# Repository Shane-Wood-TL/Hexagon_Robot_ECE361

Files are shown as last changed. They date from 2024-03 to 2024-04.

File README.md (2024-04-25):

# Hexagon Robot ECE361
 
### Shane Wood and Logan Martin 

### Final Robot
1PXL_20240423_235646060 RAW-01 COVER

### Early Render of robot
robo2

### Abstract: 
For this design project, we are planning to develop a robotics platform by creating a 3-wheeled robot. This design also includes a controller so the robot can be controlled remotely over 2.4 GHz using an NRF2401 module. Our design currently has 3 main modes planned; user control with the controller, fully autonomous (wall following), and line following. We plan to use the ESP32-S3 for the microcontrollers running on the Arduino framework for both the controller and the robot. The robot will also feature distance sensors for the autonomous modes and IR sensors for the line-following mode. The robot will have a 3d printed base and omni wheels, the project will also have 2 custom PCBs, one for the robot itself and the other for the controller. 

### Weekly Goals: 
Week of March 18th  
- Make the wiring diagram 
- Set up GitHub repository 
- 3d print wheel pieces 

Week of March 25th 
- Wire up design 
- Simple test code to verify wiring and power management 
- Design and order PCBs 
- Assemble wheels 

Week of April 1st 
- Develop the inverse kinematic model 
- Make controller code 
- 3d print robot body 

Week of April 8th 
- Finish user code mode 
- Get distance sensors and IR sensors working 

Week of April 15th 
- Test and finish all modes and the logic to switch between them 

Week of April 22nd 
- Debug remaining issues

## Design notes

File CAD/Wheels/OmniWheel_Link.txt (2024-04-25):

https://www.thingiverse.com/thing:5031000

Scaled to 175%
PLA for wheel body pieces

TPU 95A for rollers

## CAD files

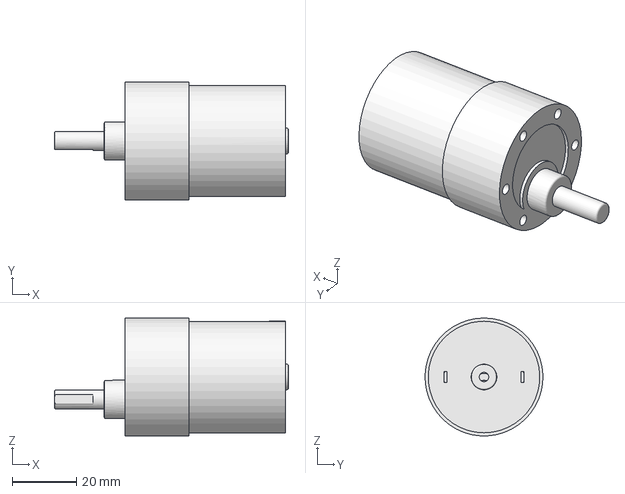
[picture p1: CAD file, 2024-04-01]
CAD/Body/assembly.FCStd
73.0 x 36.8 x 36.8 mm

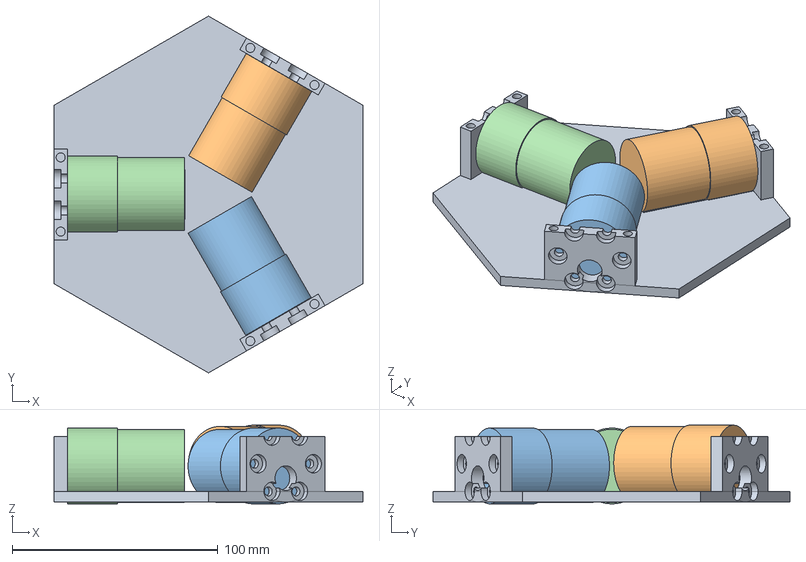
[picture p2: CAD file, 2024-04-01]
CAD/Body/oldbottom plate.FCStd
150.0 x 173.2 x 38.2 mm

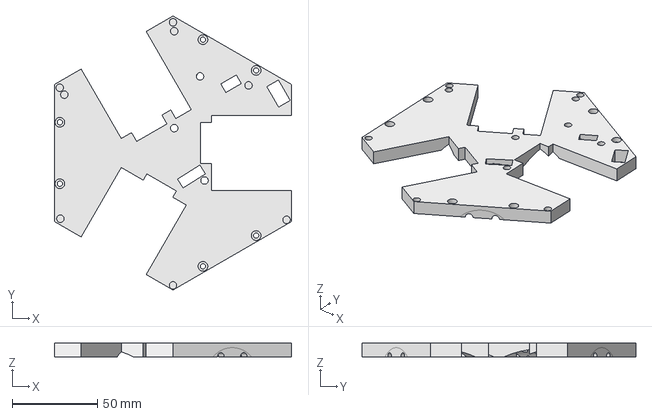
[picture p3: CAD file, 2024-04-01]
CAD/Body/2topplate.FCStd
139.0 x 160.5 x 8.00 mm

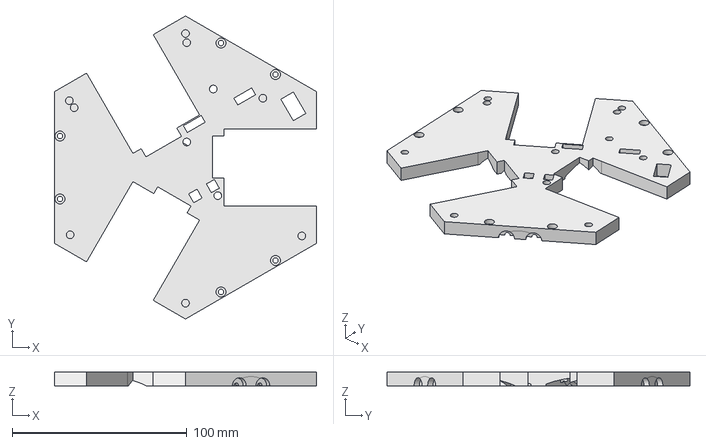
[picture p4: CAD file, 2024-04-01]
CAD/Body/topplate.FCStd
150.0 x 173.2 x 8.00 mm

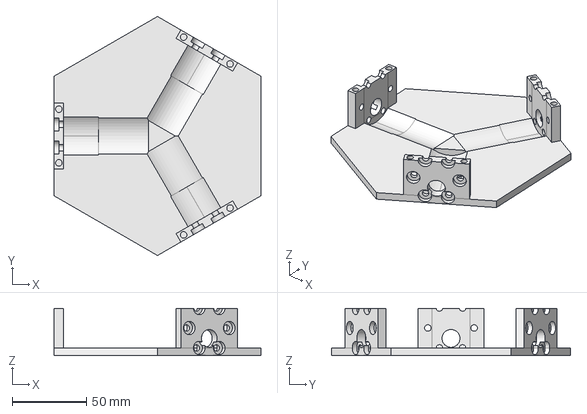
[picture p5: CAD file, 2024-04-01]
CAD/Body/V2bottom plate.FCStd
139.0 x 160.5 x 31.8 mm

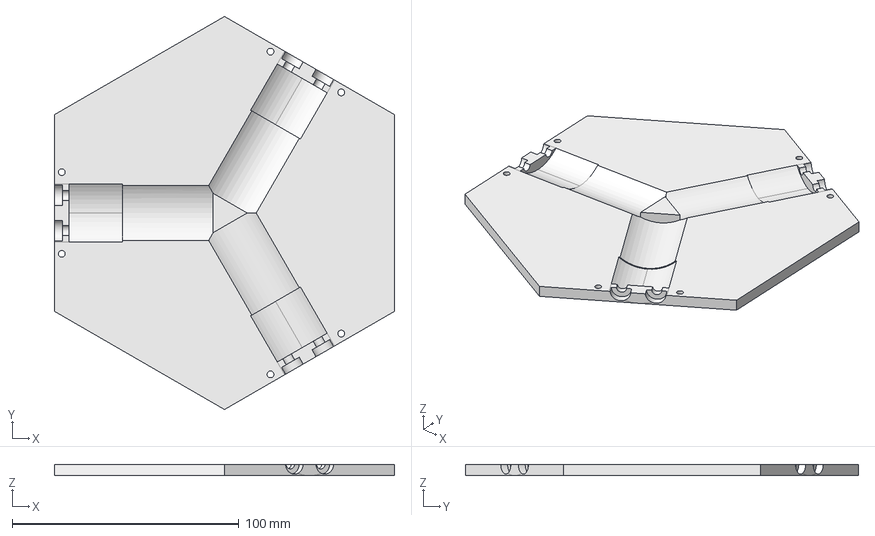
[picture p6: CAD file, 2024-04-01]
CAD/Body/bottom plate.FCStd
150.0 x 173.2 x 5.00 mm

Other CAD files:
CAD/Body/motor.FCStd

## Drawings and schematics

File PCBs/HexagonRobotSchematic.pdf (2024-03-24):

## I2C Devices

## I2C Pullup Resistors

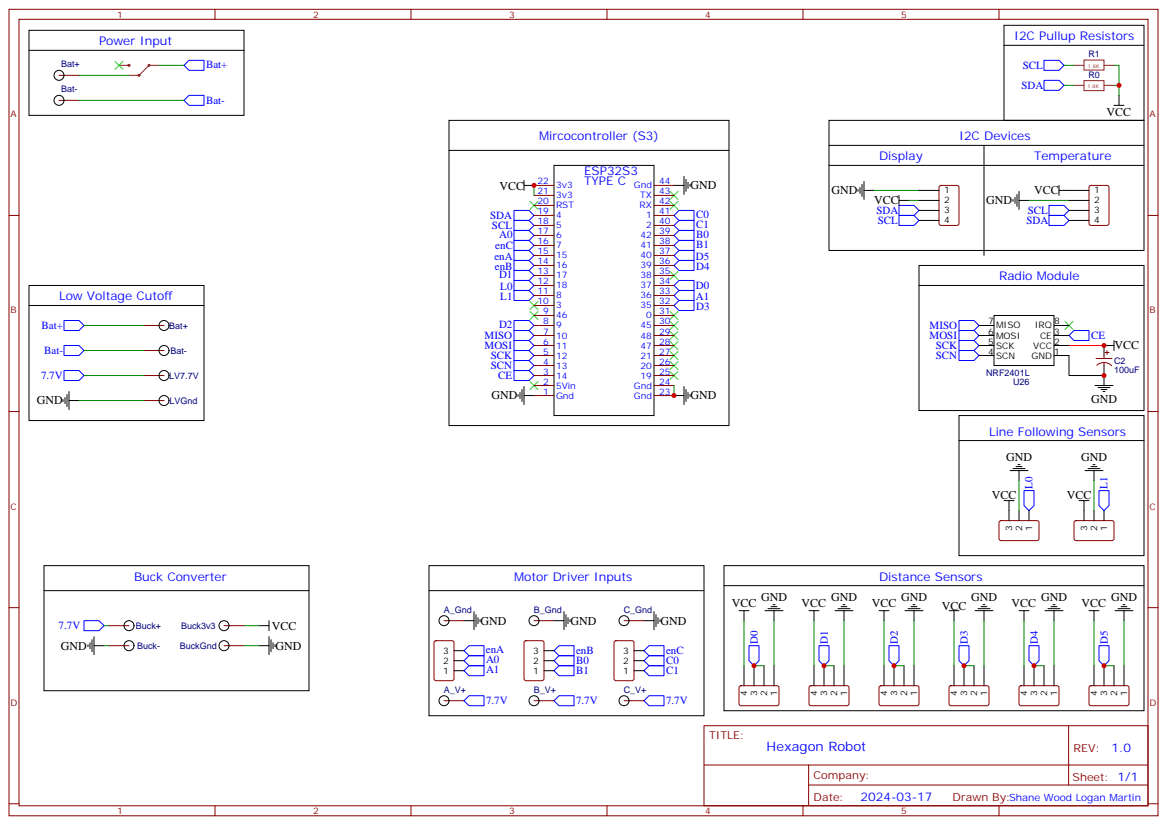
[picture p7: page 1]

Drawn By:Shane Wood Logan Martin

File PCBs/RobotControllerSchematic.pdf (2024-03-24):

## Power Input

## Low Voltage Cutoff

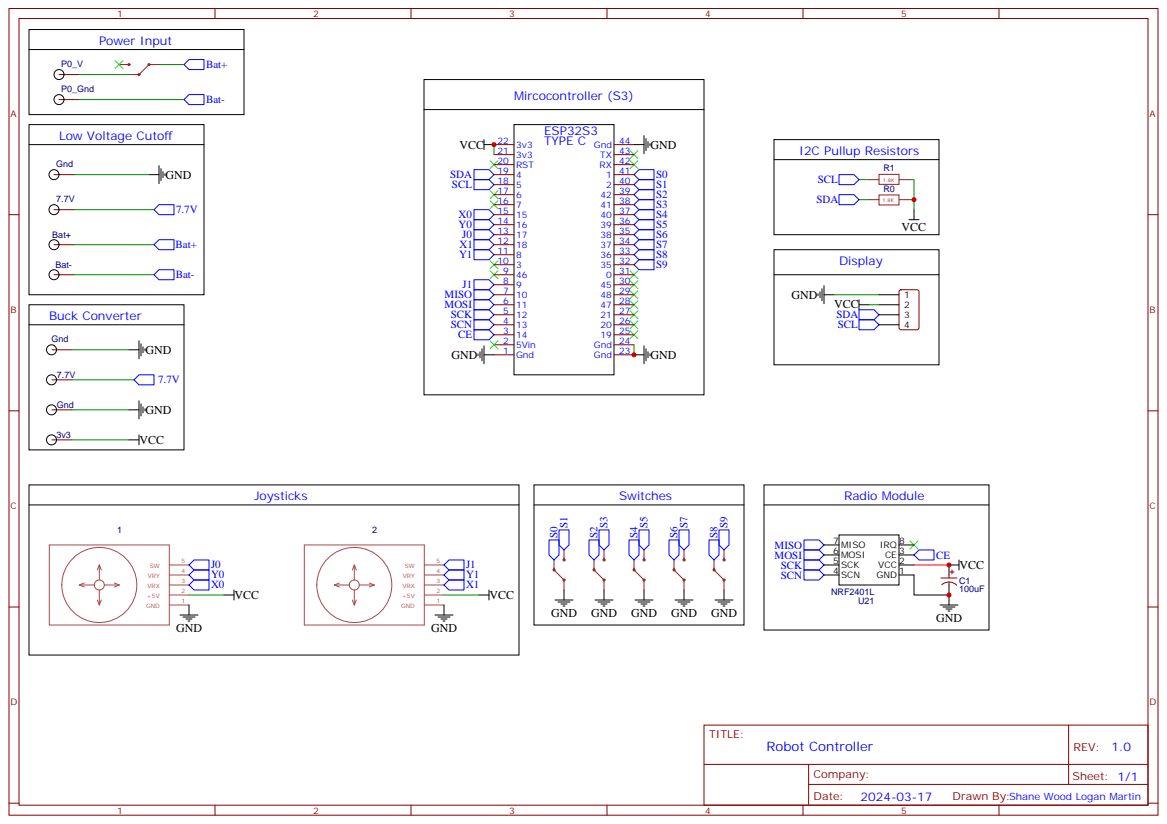
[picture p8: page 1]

Drawn By:Shane Wood Logan Martin

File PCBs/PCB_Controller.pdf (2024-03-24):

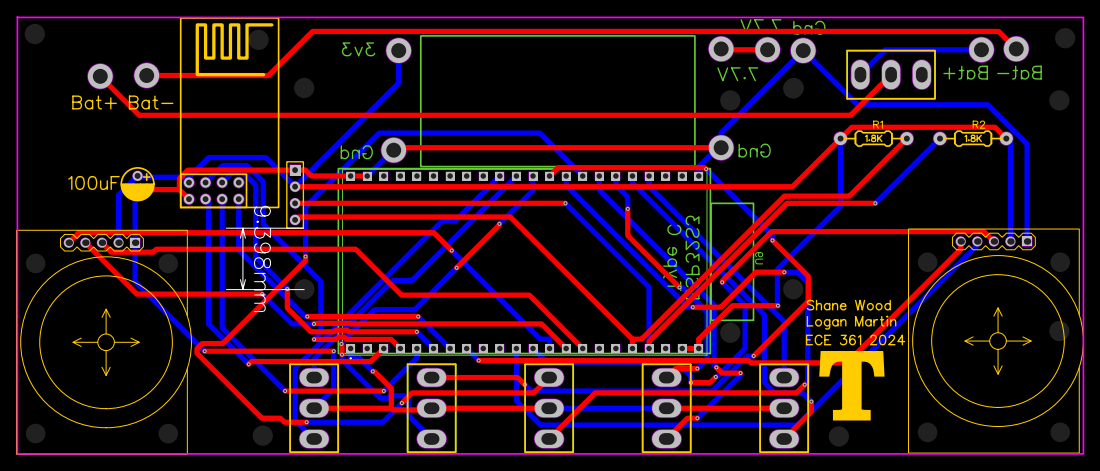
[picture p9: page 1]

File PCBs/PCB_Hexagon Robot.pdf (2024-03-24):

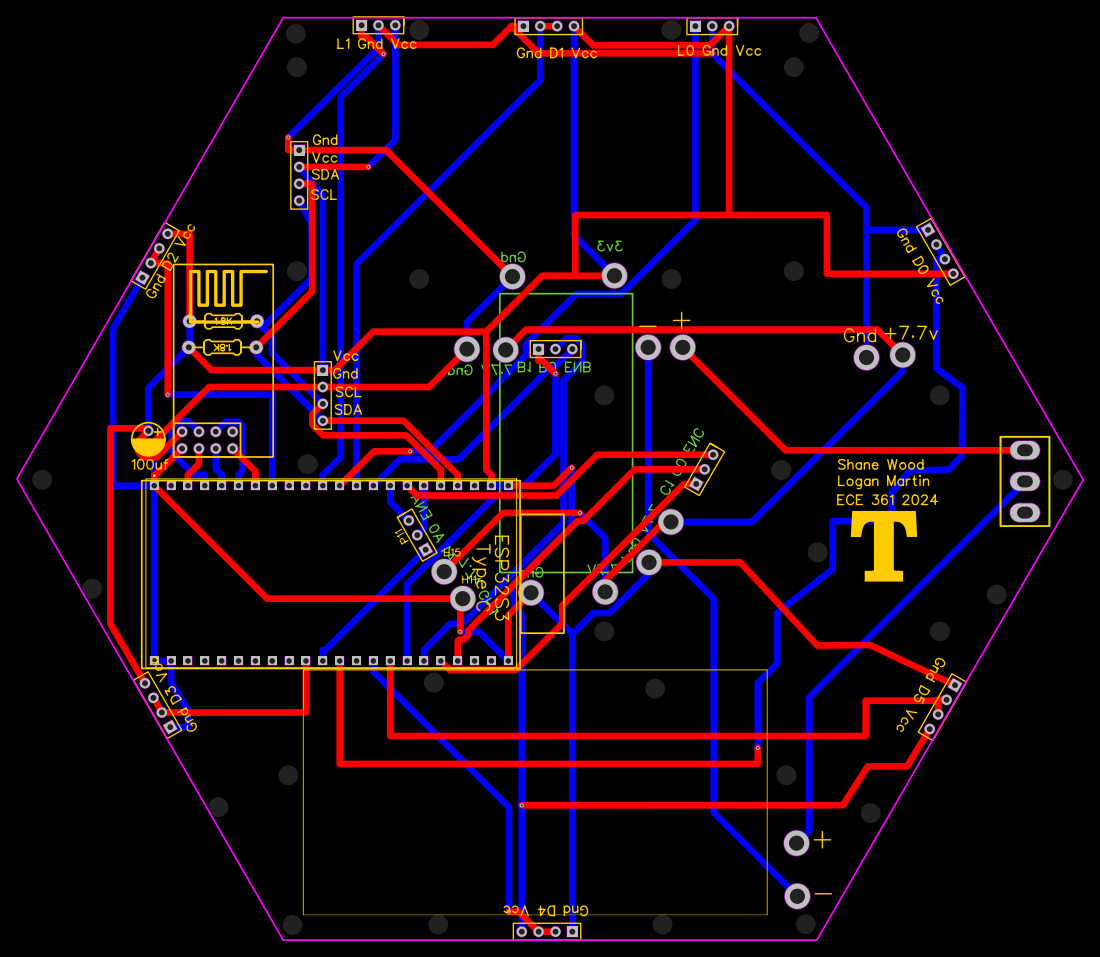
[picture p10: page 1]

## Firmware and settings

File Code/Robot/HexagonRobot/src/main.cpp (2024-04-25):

//class defintions, structures, functions and constants
#include <constants.h>

#define debugging

//motor rebalancing
float bmotorOffset = 0.9;
float aMotorOffset = 1.07;

float intialSpeedOfSound = 0.0343; //in cm/mirco second 



float v1,v2,v3; //Motor speeds


// //radio
PayloadStruct payload;
RF24 radio(CE,SCN);
bool newData = false;
int oldState = 0;
const byte address[5] = {'T','r','i','n','E'};


// //temperature sensor
Adafruit_BMP085 bmp;

// //display
LiquidCrystal_I2C lcd(0x3F,16,2);


//motor class instances
motor motorA(A0_, A1_, enA_,aChannel); //Mtr1
motor motorB(B0_, B1_, enB_,bChannel); //Mtr2
motor motorC(C0_, C1_, enC_,cChannel); //Mtr3


//distance array instance
Distances sonarArray(D0,D1,D2,D3,D4,D5,intialSpeedOfSound);


void setup() {
  #ifdef debugging
  Serial.begin(115200); //only use serial if needed
  #endif

  //i2c setup
  Wire.begin(SDA,SCL); //SDA, SCL
  lcd.init();           
  lcd.backlight();
  lcd.clear();
  lcd.print("working");
  bmp.begin();


  //begin SPI
  SPI.begin(SCK, MISO, MOSI);
  
 
  // begin radio
  if (!radio.begin()) {
    #ifdef debugging
    Serial.println(F("radio hardware is not responding!!"));
    #endif
    lcd.print("no radio");
    while (1) {}  // hold in infinite loop
  }
  radio.setPALevel(RF24_PA_MAX); //signal amplification
  radio.setDataRate(RF24_250KBPS); //transfer rate
  radio.openReadingPipe(1, address); //wireless address 
  radio.startListening(); //set receiving

  #ifdef debugging
  Serial.println("Radio Active"); 
  #endif

  //set pin directions
  pinMode(L0, INPUT);
  pinMode(L1, INPUT);

  pinMode(enA_, OUTPUT);
  pinMode(A0_, OUTPUT);
  pinMode(A1_, OUTPUT);

  pinMode(enB_, OUTPUT);
  pinMode(B0_, OUTPUT);
  pinMode(B1_, OUTPUT);

  pinMode(enC_, OUTPUT);
  pinMode(C0_, OUTPUT);
  pinMode(C1_, OUTPUT);
  
  //pwm setup
  ledcSetup(aChannel,pwmHz,pwmBit);
  ledcSetup(bChannel,pwmHz,pwmBit);
  ledcSetup(cChannel,pwmHz,pwmBit);


  ledcAttachPin(enA_, aChannel);
  ledcAttachPin(enB_, bChannel);
  ledcAttachPin(enC_, cChannel);
  #ifdef debugging
  Serial.println("setupDone");
  #endif
}

void loop() {
  //update the radio
  getData();


  //only look at the modes if not stopped
  if (payload.eStop != 1){
    //handle nomove + nospin
    switch (payload.disable){
      case 1:{
        payload.spin = noSpin;
        break;
      }
      case 2:{
        payload.speed = 0;
        break;
      }
      default:
        payload.speed = payload.speed;
        payload.spin = payload.spin;
        break;
    }

    switch(payload.mode){
      case 0:{ //user control mode
        //Dynamic direction control
        invKin(payload.speed, payload.angle, payload.spin, &v1, &v2, &v3); //map controller values to speed, direction and spin
        motorA.setSpeed(v1); //set motor speeds + direction
        motorB.setSpeed(v2*.9);
        motorC.setSpeed(v3);
        break;
      }
      case 1:{ //wall following
        moveValues wallFollow;
        wallFollow = sonarArray.wallFollow(); //get what move to make
        invKin(wallFollow.speed, wallFollow.angle, wallFollow.spin, &v1, &v2, &v3); //move
        motorA.setSpeed(v1*aMotorOffset*wallFollowStalling); //set motor speeds + direction
        motorB.setSpeed(v2*bmotorOffset);
        motorC.setSpeed(v3);
        break;
      }
      case 2:{ //line following
        int L0Value = digitalRead(L0); //Right
        int L1Value = digitalRead(L1); //Left
        moveValues LineSensor;
        LineSensor = lineFollowing(L1Value, L0Value);  //get what move to make

        //update 2 sensor values on display
        lcd.clear();
        lcd.setCursor(0,0);
        lcd.print((int)L1Value);

      
        lcd.setCursor(10,0);
        lcd.print((int)L0Value);


        //move with line follower
        invKin(LineSensor.speed,LineSensor.angle,LineSensor.spin,&v1,&v2,&v3); //move
        motorA.setSpeed(v1*aMotorOffset);//set motor speeds + direction
        motorB.setSpeed(v2);
        motorC.setSpeed(v3);

        //set timing for motors being on
        if(LineSensor.speed == 0){
          delay(150);
          //turn for 150 ms
          invKin(0,0,127, &v1, &v2, &v3);
        }else{
          delay(15);
          //drive for 15ms
          invKin(0,0,127, &v1, &v2, &v3);
        }
        motorA.setSpeed(v1*aMotorOffset);
        motorB.setSpeed(v2);
        motorC.setSpeed(v3);
        break;
      }
    }
  }else{
    //stop motors on stop
    motorA.brake();
    motorB.brake();
    motorC.brake();

    //only update temperature when stopped
    sonarArray.updateTemp(bmp.readTemperature());
  }

}

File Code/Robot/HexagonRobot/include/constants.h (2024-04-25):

#include <Arduino.h>

//distance sensor library
#include <NewPing.h>

//radio libraries
#include <SPI.h>
#include <nRF24L01.h>
#include <RF24.h>

//line following library
#include <PID_v1.h> 

//wall following library
#include <math.h>

//temp + display libraries
#include <Wire.h>
#include <Adafruit_BMP085.h>
#include <LiquidCrystal_I2C.h>


//all constant pin declarations

//I2C pins
#define SDA 4
#define SCL 5


//motor output pins
#define A0_ 6
#define A1_ 36
#define enA_ 15

#define B0_ 42
#define B1_ 41
#define enB_ 16

#define C0_ 1
#define C1_ 2
#define enC_ 7


//internal pwm channel numbers
#define aChannel 0
#define bChannel 3
#define cChannel 6


//pwm values
#define pwmHz 1000
#define pwmBit 8

//distance sensor input output pins
#define D0 37
#define D1 19
#define D2 9
#define D3 35
#define D4 39
#define D5 40


//spi pins
#define MISO 10
#define MOSI 11
#define SCK 12
#define SCN 13
#define CE 14


//line following pins
#define L0 18
#define L1 8


//joystick settings
#define JOYSTICK_CENTER 128
#define PWM_FREQ 1000

//max distance measured by hc-sr04
#define maxDistance 70


//base increase to pwm signal
#define pwmGain 20

#define bit8Max 255


#define noSpin 127 //value where spin is zeroed

#define lineFollowingSpeed 230 //max speed when line following
#define wallFollowStalling 0.6 //wall following needs a motor to stall partially to work


//display defined in main.cpp
extern LiquidCrystal_I2C lcd;

//radio from main
extern RF24 radio;


//struct to send movement values to main
struct moveValues{
  float speed;
  float angle;
  float spin;
};


//struct from the controller
struct PayloadStruct {
  uint8_t mode;   //simple mode, basic int
  float speed; //a int centered at 127
  float angle; //a int centered at 127
  uint8_t spin = 127;   //a int centered at 127
  uint8_t eStop;  // bascially a bool
  uint8_t disable;
};

extern PayloadStruct payload; //payload struct from main

//motor class, handles direction given a +- value and speed
class motor{
  private:
    int P0;
    int P1;
    int enP;
    int channel;
  public:
    motor(int P0V, int P1V, int enPV, int channelV){
      P0 = P0V;
      P1 = P1V;
      enP = enPV;
      channel = channelV;
    }
    void setSpeed(float speed){
      if(speed == 0){
        brake();
      }else if (speed > 0){
        //move forwards
        digitalWrite(P0, HIGH);
        digitalWrite(P1, LOW);
        //bumping up the min signal by gain
        if(abs(speed) >= 235){
          speed = 235;
        }
        ledcWrite(channel, constrain(abs(speed)+pwmGain, 0, bit8Max));
      }else if (speed < 0){
        //move backwards
        digitalWrite(P0, LOW);
        digitalWrite(P1, HIGH);
        //bumping up the min signal gain
        ledcWrite(channel,constrain(abs(speed)+pwmGain, 0, bit8Max));
      }
    }
    void brake(){
      //stop motor
      digitalWrite(P0, HIGH);
      digitalWrite(P1, HIGH);
    }
};




//class that handles the distance sensor code
class DistanceSensor{
  private:
    NewPing sonar;
    float speed;
    float distance;
  public:
    DistanceSensor(int pinV, float speedV) : sonar(pinV, pinV, maxDistance), speed(speedV) {
    }

    float getDistance(){
      //run sensor once
      float duration = sonar.ping_median(1);
      //instant hit (does not work correctlly / impossible or out of range)
      if (duration == 0){
        return 0;
      }
      //only get one path (duration has sending and receiving time)
      //mutiply by current speed of sound to get cm
      distance = (duration / 2) * speed;
      return distance;
    }
    void setSpeed(float speedV){
      //set the speed of sound
      speed = speedV;
    }
};
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

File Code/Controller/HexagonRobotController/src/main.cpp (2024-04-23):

#include <constants.h>

//#define debugging

//radio variables
PayloadStruct payload;
RF24 radio(CE,SCN);
bool newData = false;
const byte radioAddress[5]  = {'T','r','i','n','E'};


//display object
LiquidCrystal_I2C lcd(0x3F,16,2);

//all inputs in a struct
inputValues readingValues;

//old and present state (used to prevent extra display refreshes)
int oldState = 0;
int state = 0;

void setup() {
  #ifdef debugging
  //Start serial
  Serial.begin(115200);
  #endif

  //start i2c
  Wire.begin(SDA,SCL);

  //setup display
  lcd.init();           
  lcd.backlight();
  lcd.clear();
  lcd.print("working ");


  //start spi
  SPI.begin(SCK, MISO, MOSI);
  radio.begin();
  
  // begin radio
  if (!radio.begin()) {
    #ifdef debugging
      Serial.println(F("radio hardware is not responding!!"));
    #endif
    lcd.print("no radio");
    while (1) {}  // hold in infinite loop
  }
  //radio.printPrettyDetails();
  
  //set radio speed, and wireless address
  radio.setDataRate( RF24_250KBPS );
  radio.setRetries(3,5); // delay, count
  radio.setPALevel(RF24_PA_MIN);
  radio.openWritingPipe(radioAddress);

  //display that radio working
  lcd.clear();
  lcd.print("radio working");

  //setup all input pins
  pinMode(S0, INPUT_PULLUP);
  pinMode(S1, INPUT_PULLUP);
  pinMode(S2, INPUT_PULLUP);
  pinMode(S3, INPUT_PULLUP);
  pinMode(S4, INPUT_PULLUP);
  pinMode(S5, INPUT_PULLUP);
  pinMode(S6, INPUT_PULLUP);
  pinMode(S7, INPUT_PULLUP);
  pinMode(S8, INPUT_PULLUP);
  pinMode(S9, INPUT_PULLUP);

  pinMode(X0, INPUT);
  pinMode(Y0, INPUT);
  pinMode(J0, INPUT);
  pinMode(X1, INPUT);
  pinMode(Y1, INPUT);
  pinMode(J1, INPUT);
}

void loop() {
  //update input values
  updateAll(readingValues);

  //update estop
  if(readingValues.S8V != 1){
    if(payload.eStop != 1){
      payload.eStop = 1;
      updateMenu(state, payload);
    }
  }else{
    if(payload.eStop != 0){
      payload.eStop = 0;
      updateMenu(state, payload);
    }
  }


  //3 and 2 (disable spin, disable move)
  // no disable = 0
  // spin disable = 1
  // move disable = 2
  if(readingValues.S2V != 1){
    //spin disable
    if(payload.disable != 1){
      payload.disable = 1;
      updateMenu(state, payload);
    }
  }else if(readingValues.S3V != 1){
    //move disable
    if(payload.disable != 2){
      payload.disable = 2;
      updateMenu(state, payload);
    }
  }else{
    if(payload.disable != 0){
      payload.disable = 0;
      updateMenu(state, payload);
    }
  }
  


  //once mode switching is done switch modes
  if (state != oldState && readingValues.S6V == 1){
    oldState = state;
    payload.mode = oldState;    
  }

  //menu interface to switch modes
  if(readingValues.S6V != 1){
    float menuJ = map(readingValues.J0YV, 0,4096,-80,80);
    int temp_state = state;

      if(menuJ >=75){
        state = decState(state);
        delay(200);
      }else if(menuJ <= -75){
        state = incState(state);
        delay(200);
      }
      if(temp_state!=state){
        updateMenu(state, payload);
      }
    
  }




  //the rest of the values to be sent through payload can be set here like
  
  //joystick mapping + zeroing
  float adjustedX = constrain((map(readingValues.J0XV, 0, 4096, 255,-255)-6), -255, 255);
  float adjustedY = constrain((map(readingValues.J0YV, 0, 4096, 255,-255)+4), -255, 255);
  float speed = sqrt(pow(adjustedX,2)+ pow(adjustedY,2));
  float angle = atan2(adjustedY, adjustedX);

  angle = angle * (180.0/3.14);
  if (angle < 0){
    angle +=360;
  }
  payload.angle = angle;
  payload.speed= speed;


  int j1x = 127;
  if (readingValues.J1XV >= 3300){
    j1x = constrain(int(map(readingValues.J1XV, 3300, 4096, 127,0)), 0, 255);
  }else{
    j1x = constrain(int(map(readingValues.J1XV, 3329, 340, 127,255)), 0, 255);
  }
  payload.spin = j1x;


  radio.write(&payload, sizeof(PayloadStruct)); //actually send values
}



//function to update all inputs on the controller
void updateAll(inputValues &values){
  values.S0V = digitalRead(S0);
  values.S1V = digitalRead(S1);
  values.S2V = digitalRead(S2);
  values.S3V = digitalRead(S3);
  values.S4V = digitalRead(S4);
  values.S5V = digitalRead(S5);
  values.S6V = digitalRead(S6);
  values.S7V = digitalRead(S7);
  values.S8V = digitalRead(S8);
  values.S9V = digitalRead(S9);

  values.J0JV = digitalRead(J0);
  values.J1JV = digitalRead(J1);

  values.J0XV = analogRead(X0);
  values.J0YV = analogRead(Y0);
  values.J1XV = analogRead(X1);
  values.J1YV = analogRead(Y1);
}

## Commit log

2024-03-18 Added empty projects and folder structure
    Created platformio projects for the 3 microcontrollers in this project. Added in progress schematic.
2024-03-18 Finished Schematics
2024-03-18 Adding PDFs of the schematics
2024-03-23 Basic Motor Testing
2024-03-23 Added structs for motor + distance sensor
2024-03-23 Added overall distance library with math for wall following
    Added a class that builds on the distance classes that finds the nearest wall, and the 2 adjacent sensors. Also added the math to convert the 45 deg measurements to base line.
2024-03-24 Add base code for wireless communication, start controller code
    Added pin definitions for the controller, added base transmit code + display code for the controller. Fixed temperature dependent distance measurements.
    [constants.h, main.cpp]
2024-03-24 Added final schematics + PCB files
2024-03-24 Added Cad files + blender test file
    [assembly.FCStd, bottom plate.FCStd, topplate.FCStd]
2024-03-25 Finished CAD for robot
    [assembly.FCStd, bottom plate.FCStd, topplate.FCStd]
2024-04-01 Fixed pwm + updated cad
    [2topplate.FCStd, V2bottom plate.FCStd, assembly.FCStd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]
2024-04-02 added more pwm test code
2024-04-02 Attempting to get other movement working
    PWM is not linearly mapping to speed leading to unexpected behavior
2024-04-08 Inverse Kinematics Update
    I put the equation you sent me into the invkin function.
    I also set up a dynamic decision on what direction the wheels should spin.
    On top of that I commented out the previous IK equations and I also put a version of the IK with decimal values and commented this out as well.
2024-04-08 Added webserver files for camera
2024-04-08 Camera Main Code
2024-04-08 typed wrong values in last push
    [main.cpp]
2024-04-09 All basic sensors working
    Fixed DistanceSensor Class
    [constants.h, main.cpp]
2024-04-09 IK + Sensors
    Got IK working with user control
2024-04-09 set up camera
    yes
2024-04-19 Current wall and line following code
2024-04-25 Updated Wheel Link
2024-04-25 Final Code Commit + Cad update
